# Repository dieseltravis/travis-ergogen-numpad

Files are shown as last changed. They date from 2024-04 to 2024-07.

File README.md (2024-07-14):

# travis-ergogen-numpad
A numpad made with Ergogen v4 and SMD components. *Alpha* quality!

keyboard combo outline

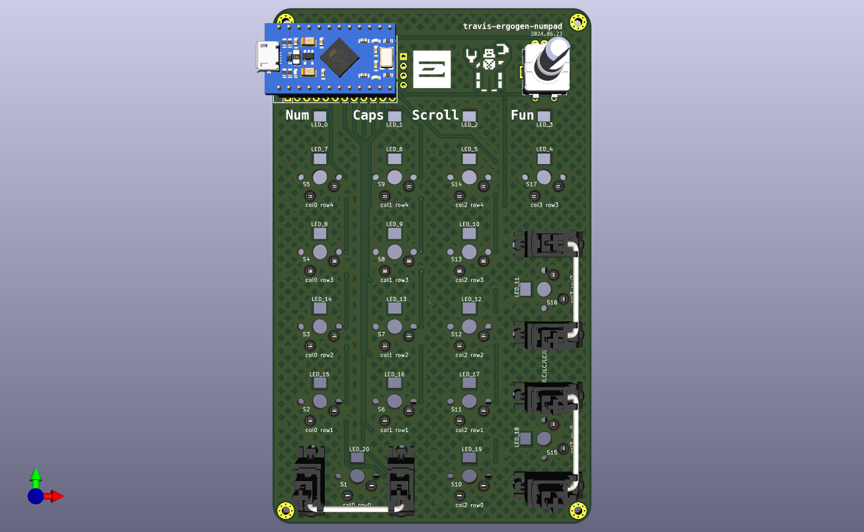
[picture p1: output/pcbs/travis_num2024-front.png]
PCB front


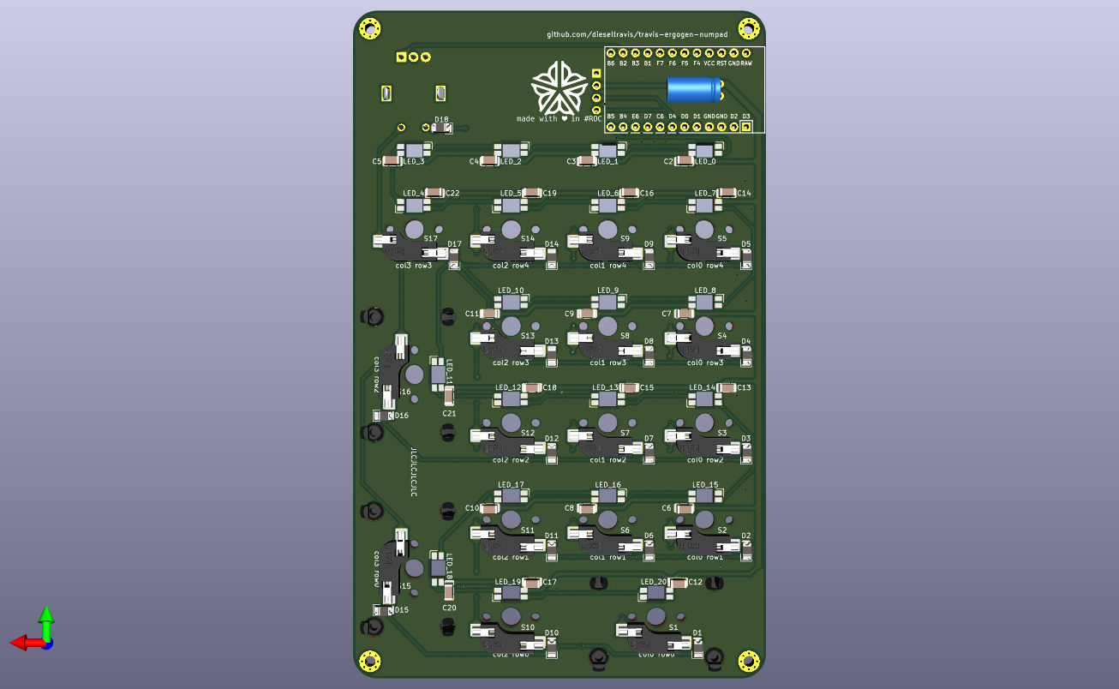
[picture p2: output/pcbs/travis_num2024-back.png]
PCB back


## Parts ##

JLCPCB PCBA:
* 17 @ C5184526 Kailh CPG151101S11-1 Mechanical Keyboard Shaft ROHS https://jlcpcb.com/partdetail/Kailh-CPG151101S111/C5184526
* 18 @ C7420318 hongjiacheng 1N4148W SOD-123 Switching Diode ROHS https://jlcpcb.com/partdetail/hongjiacheng-1N4148W/C7420318
* 21 @ C5149201 OPSCO Optoelectronics SK6812MINI-E SMD RGB LEDs(Built-in IC) ROHS https://jlcpcb.com/partdetail/OPSCOOptoelectronics-SK6812MINIE/C5149201
* 21 @ C710467 HUI JU NM1206B104K251CEGN 100nF X7R ±10% 1206 Multilayer Ceramic Capacitors MLCC - SMD/SMT ROHS https://jlcpcb.com/partdetail/HUIJU-NM1206B104K251CEGN/C710467
* C4747954 KNSCHA RST470UF10V029 470uF 10V 260mA@120Hz ±20% SMD,D6.3xL7.7mm Aluminum Electrolytic Capacitors - SMD ROHS https://jlcpcb.com/partdetail/KNSCHA-RST470UF10V029/C4747954

Aliexpress:
* Rotary encoder: EC11 12.5mm 5pcs https://www.aliexpress.us/item/2251832789732148.html
* RP2040 Pro Micro 16M https://www.aliexpress.us/item/3256805943704472.html
* 0.91 Inch OLED Module 0.91" White Blue 128X32 https://www.aliexpress.us/item/3256805787666312.html

Adafruit:
* 2 @ Kailh Mechanical Key Switches - Tactile Brown - 10 pack - Cherry MX Brown Compatible https://www.adafruit.com/product/4954
* Woven USB Cable with USB A to Right Angle USB C https://www.adafruit.com/product/5031

## References ##

* [sadekbaroudi's QMK RGB Matrix configuration](https://github.com/sadekbaroudi/keyboard-guides/blob/master/firmware/qmk/RGB_MATRIX/RGB_MATRIX.md)
* [my first KB](https://github.com/dieseltravis/travis-ergogen-2024/)

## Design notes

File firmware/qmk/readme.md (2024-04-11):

# dieseltravis/travisergonum

dieseltravis/travisergonum

Ergogen numpad with encoder and screen.

* Keyboard Maintainer: [Travis Hardiman](https://github.com/dieseltravis)
* Hardware Supported: *The PCBs, controllers supported*
* Hardware Availability: *Links to where you can find this hardware*

Make example for this keyboard (after setting up your build environment):

    make dieseltravis/travisergonum:default

Flashing example for this keyboard:

    make dieseltravis/travisergonum:default:flash

See the [build environment setup](https://docs.qmk.fm/#/getting_started_build_tools) and the [make instructions](https://docs.qmk.fm/#/getting_started_make_guide) for more information. Brand new to QMK? Start with our [Complete Newbs Guide](https://docs.qmk.fm/#/newbs).

## Bootloader

Enter the bootloader in 3 ways:

* **Bootmagic reset**: Hold down the key at (0,0) in the matrix (usually the top left key or Escape) and plug in the keyboard
* **Physical reset button**: Briefly press the button on the back of the PCB - some may have pads you must short instead
* **Keycode in layout**: Press the key mapped to `QK_BOOT` if it is available

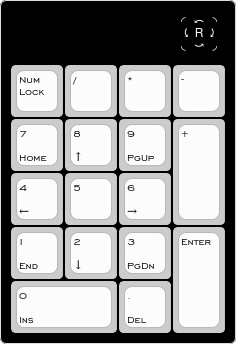
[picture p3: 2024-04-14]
kle/travis-ergonum.png

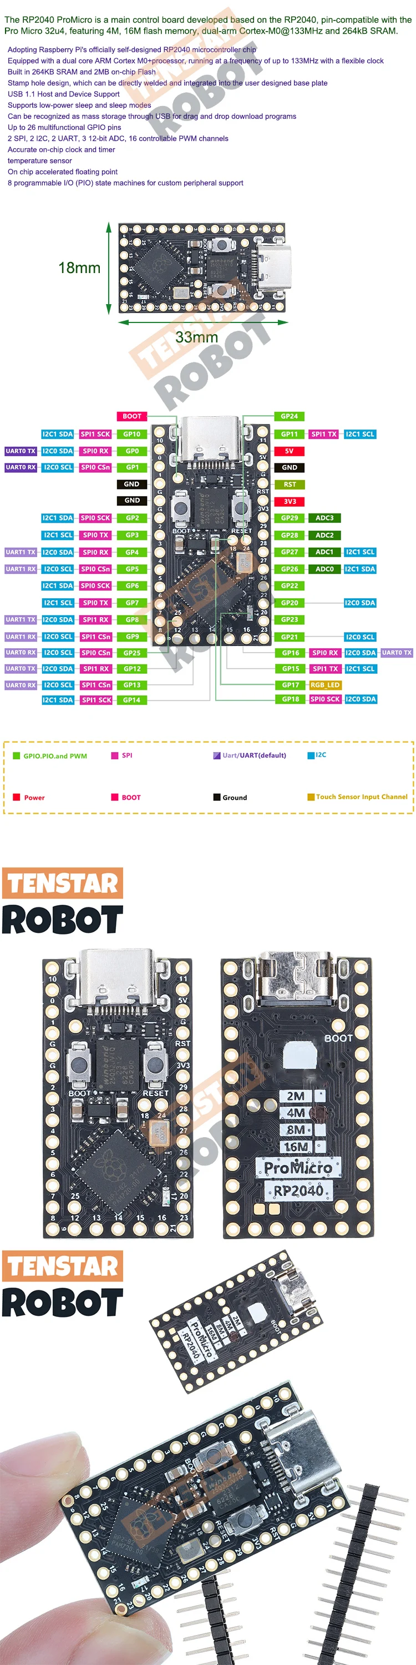
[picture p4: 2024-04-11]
datasheets/rp2040-promicro.webp

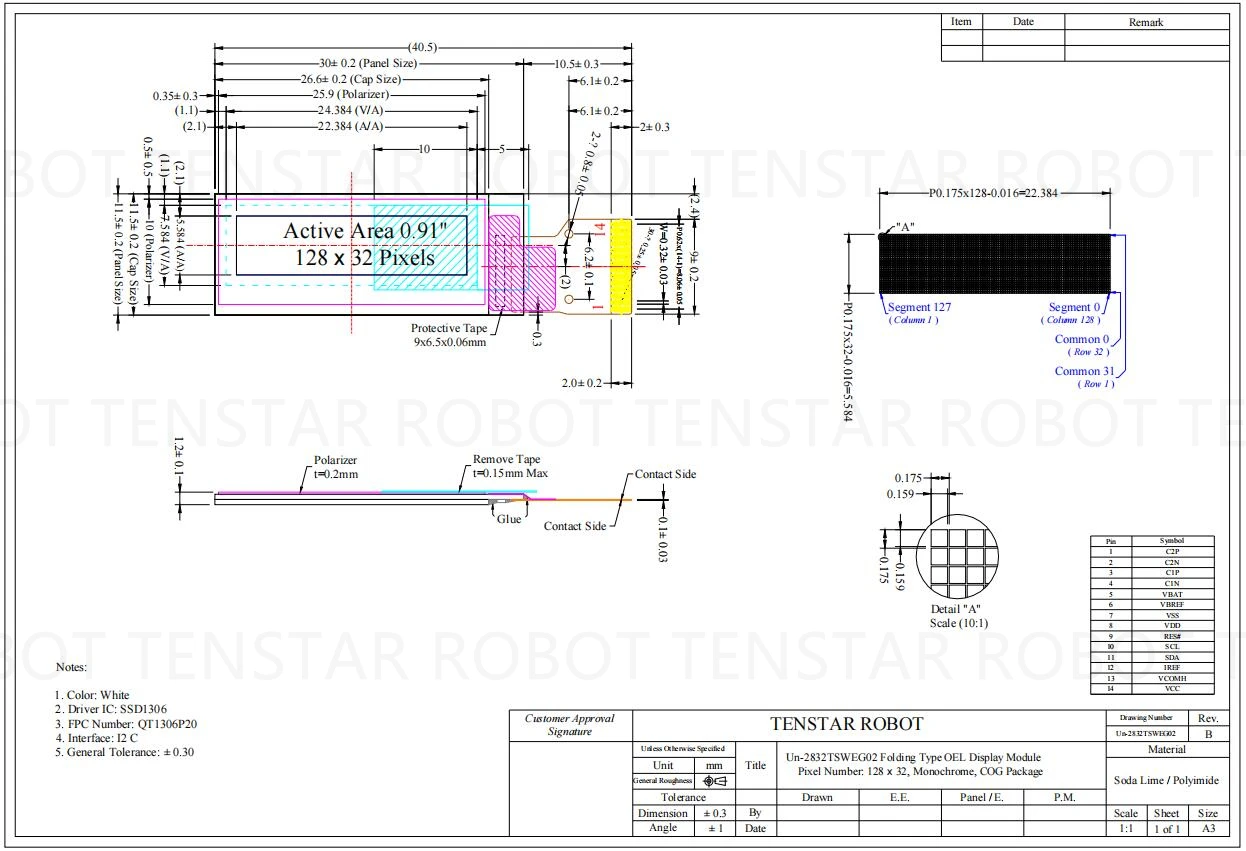
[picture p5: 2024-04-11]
datasheets/ssd1306-128x32.webp

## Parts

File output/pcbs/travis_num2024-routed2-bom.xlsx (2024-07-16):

Id | Designator | Footprint | Quantity | Designation | JLCPCB Part #（optional）
1 | S5,S14,S2,S17,S3,S8,S15,S6,S11,S12,S1,S9,S10,S7,S13,S16,S4 | MX | 17 | Kailh MX Switch Sockets | C5184526
7 | LED_0,LED_12,LED_5,LED_17,LED_3,LED_15,LED_2,LED_1,LED_7,LED_19,LED_18,LED_8,LED_13,LED_4,LED_6,LED_16,LED_9,LED_20,LED_10,LED_14,LED_11 | led_SK6812mini-e (per-key, single-side) | 21 | SK6812mini-e | C5149201
8 | C14,C2,C21,C13,C5,C17,C3,C20,C9,C15,C11,C8,C7,C16,C10,C18,C4,C19,C22,C12,C6 | C_1206_3216Metric | 21 | C_1206_3216Metric | C710467
9 | D3,D18,D14,D6,D17,D8,D1,D16,D12,D2,D13,D4,D10,D9,D15,D5,D11,D7 | D_1206_3216Metric | 18 | D_1206_3216Metric | C7420318

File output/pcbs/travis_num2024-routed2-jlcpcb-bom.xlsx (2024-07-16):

Comment | Designator | Footprint | JLCPCB Part #（optional）
Kailh MX Switch Sockets | S5,S14,S2,S17,S3,S8,S15,S6,S11,S12,S1,S9,S10,S7,S13,S16,S4 | MX | C5184526
SK6812mini-e | LED_0,LED_12,LED_5,LED_17,LED_3,LED_15,LED_2,LED_1,LED_7,LED_19,LED_18,LED_8,LED_13,LED_4,LED_6,LED_16,LED_9,LED_20,LED_10,LED_14,LED_11 | led_SK6812mini-e (per-key, single-side) | C5149201
C_1206_3216Metric | C14,C2,C21,C13,C5,C17,C3,C20,C9,C15,C11,C8,C7,C16,C10,C18,C4,C19,C22,C12,C6 | C_1206_3216Metric | C710467
D_1206_3216Metric | D3,D18,D14,D6,D17,D8,D1,D16,D12,D2,D13,D4,D10,D9,D15,D5,D11,D7 | D_1206_3216Metric | C7420318

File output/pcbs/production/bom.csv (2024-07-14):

Designator | Footprint | Quantity | Value | LCSC Part #
C1 | C_Radial_D6.3mm_H11.0mm_P2.50mm | 1 | 6.3V 1000uF
C10, C11, C12, C13, C14, C15, C16, C17, C18, C19, C2, C20, C21, C22, C3, C4, C5, C6, C7, C8, C9 | 1206 | 21 | C_1206_3216Metric
D1, D10, D11, D12, D13, D14, D15, D16, D17, D18, D2, D3, D4, D5, D6, D7, D8, D9 | 1206 | 18 | D_1206_3216Metric
HOLE1, HOLE2, HOLE3, HOLE4 | MountingHole_2.2mm_M2_Pad_Via | 4
LED_0, LED_1, LED_10, LED_11, LED_12, LED_13, LED_14, LED_15, LED_16, LED_17, LED_18, LED_19, LED_2, LED_20, LED_3, LED_4, LED_5, LED_6, LED_7, LED_8, LED_9 | led_SK6812mini-e (per-key, single-side) | 21 | SK6812mini-e
MCU1 | Arduino_Pro_Micro | 1 | Arduino Pro Micro
OLED1 | OLED_headers | 1 | OLED
ROT1 | ec11 | 1 | EC11
S1, S10, S11, S12, S13, S14, S15, S16, S17, S2, S3, S4, S5, S6, S7, S8, S9 | MX | 17 | Kailh MX Switch Sockets

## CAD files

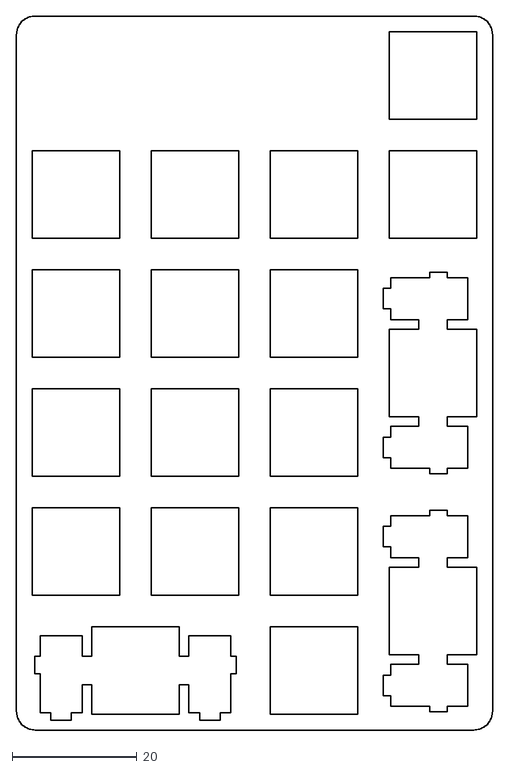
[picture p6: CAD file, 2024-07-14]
kle/plate.dxf
76.2 x 114.3

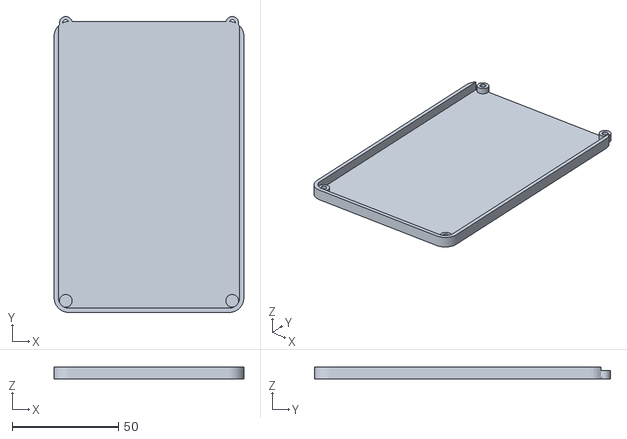
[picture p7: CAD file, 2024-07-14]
output/cases/case.stl
89.2 x 139.1 x 5.60

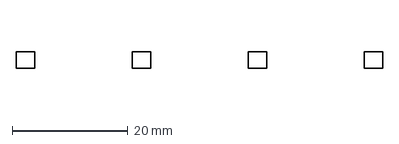
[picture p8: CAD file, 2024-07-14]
output/outlines/leds.dxf
63.4 x 2.80 mm

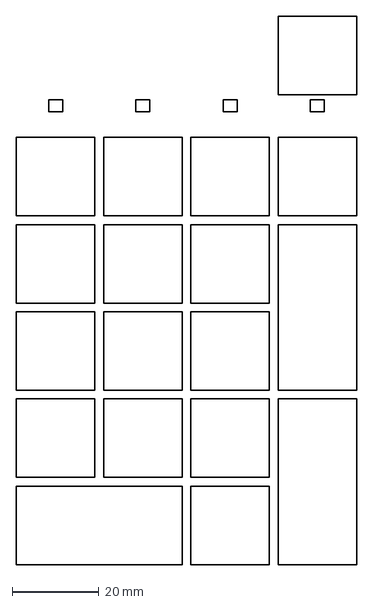
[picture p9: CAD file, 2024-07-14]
output/points/demo.dxf
78.2 x 126.1 mm

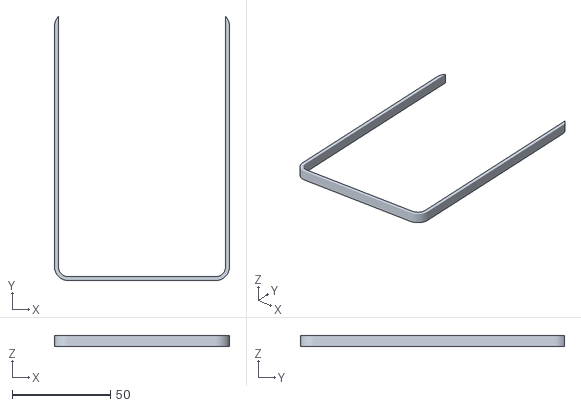
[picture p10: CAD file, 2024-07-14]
output/cases/wall.stl
89.2 x 134.6 x 5.60

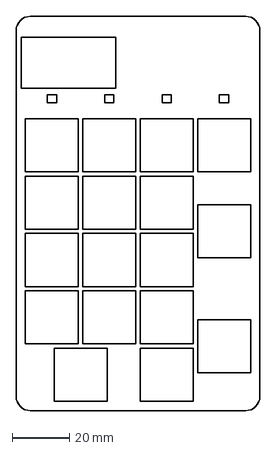
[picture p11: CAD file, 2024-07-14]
output/outlines/combo.dxf
85.2 x 137.8 mm

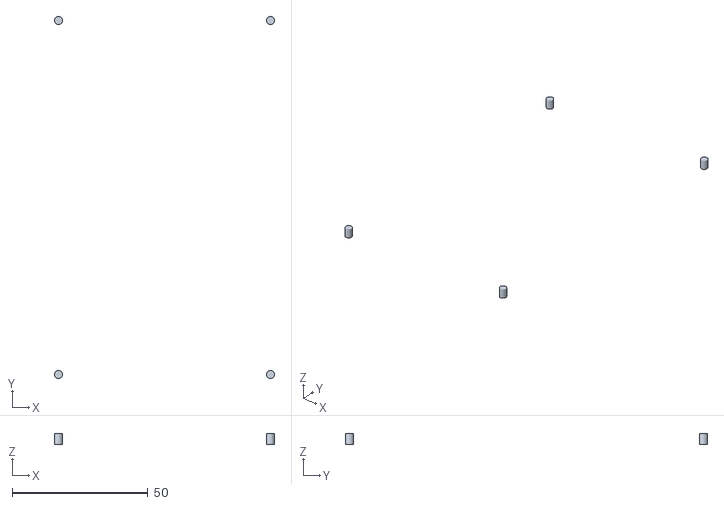
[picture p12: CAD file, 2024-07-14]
output/cases/_holes.stl
81.2 x 133.6 x 4.00

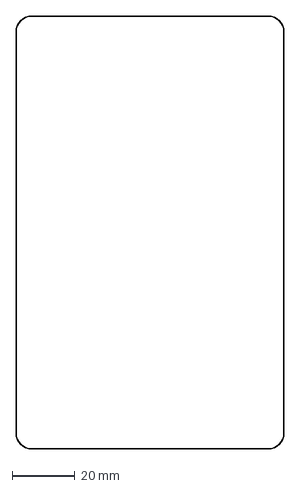
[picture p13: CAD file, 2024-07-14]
output/outlines/board.dxf
85.2 x 137.8 mm

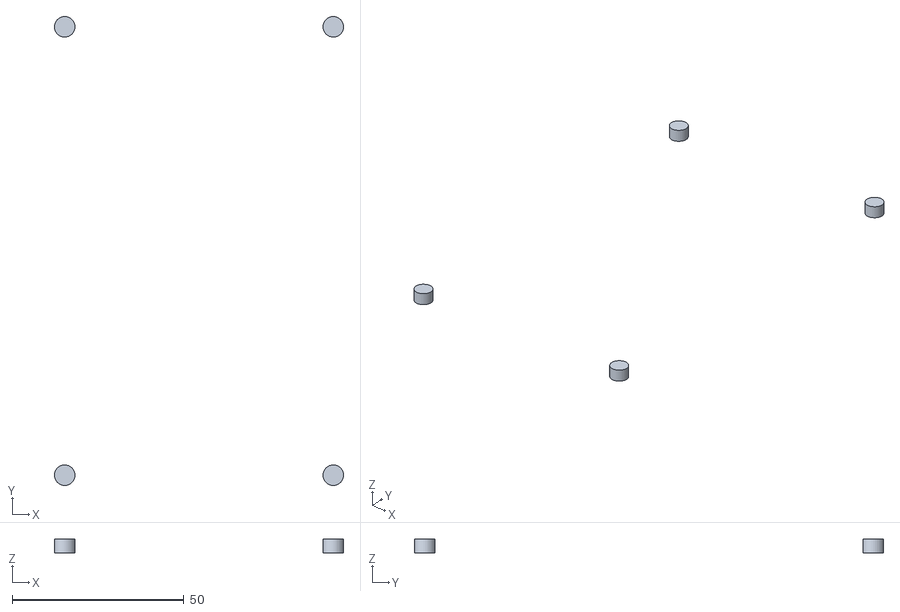
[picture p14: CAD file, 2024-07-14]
output/cases/_standoffs.stl
84.2 x 136.6 x 4.00

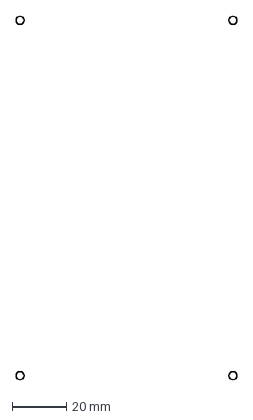
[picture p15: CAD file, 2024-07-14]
output/outlines/mounting.dxf
81.2 x 133.6 mm

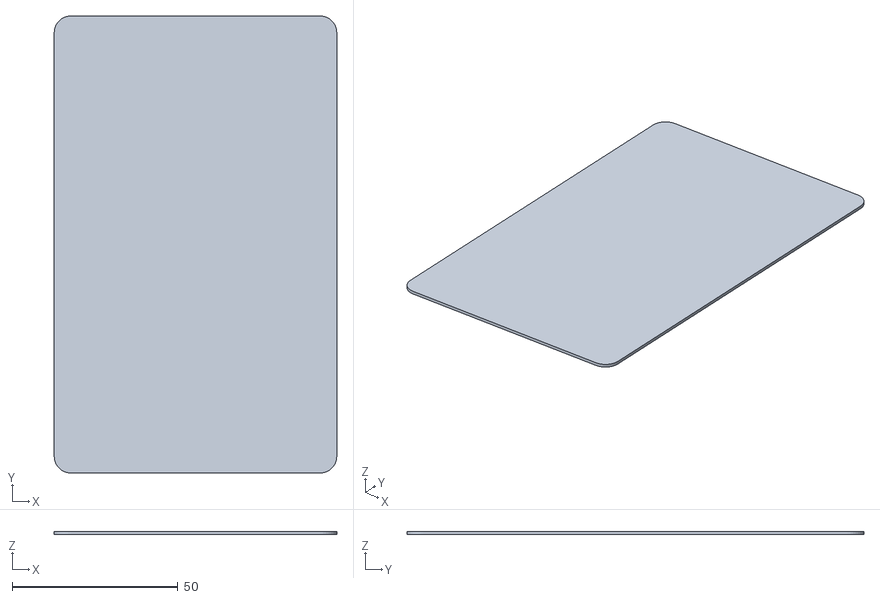
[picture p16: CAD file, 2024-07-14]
output/cases/bottom.stl
85.2 x 137.8 x 1.00

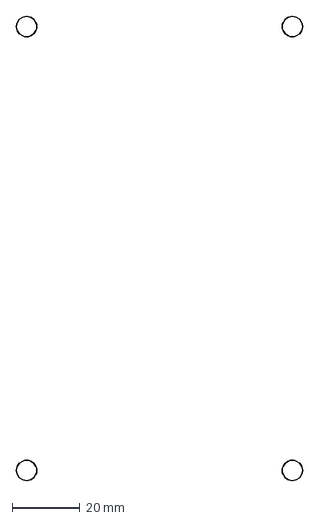
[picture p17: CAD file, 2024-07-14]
output/outlines/standoff.dxf
84.2 x 136.6 mm

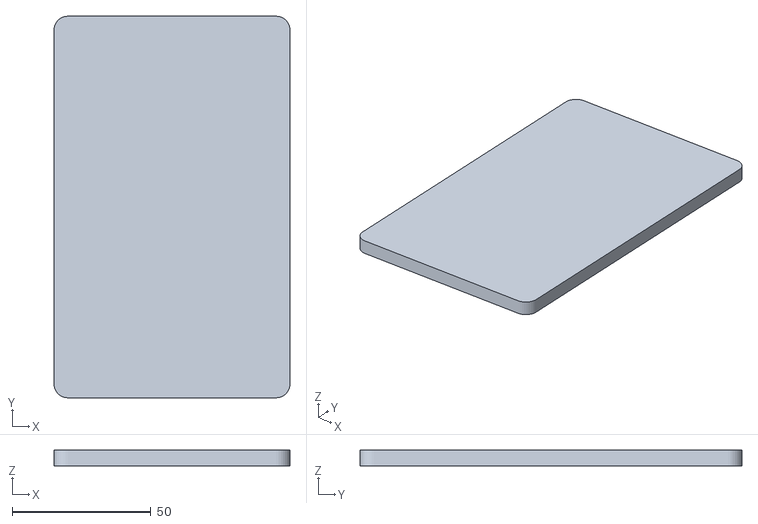
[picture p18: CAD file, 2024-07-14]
output/cases/_innerWall.stl
85.2 x 137.8 x 5.60

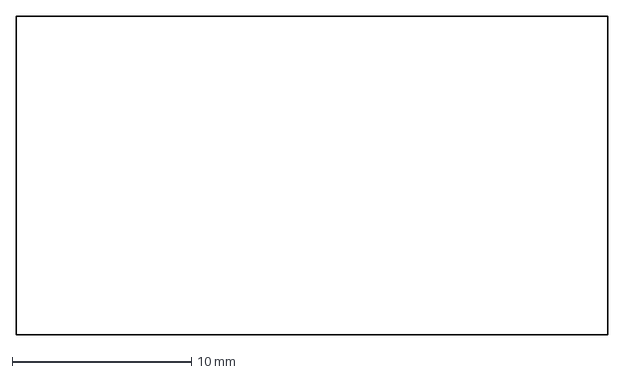
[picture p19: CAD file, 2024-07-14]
output/outlines/mcu.dxf
33.0 x 17.8 mm

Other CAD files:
output/cases/plate.stl
output/outlines/plate.dxf
output/cases/_outerWall.stl
output/outlines/2u_stabilizer.dxf
output/cases/xlBottom.stl
output/outlines/_raw.dxf
output/outlines/keyholes.dxf
output/outlines/keys.dxf
output/outlines/raw.dxf
output/outlines/smBoard.dxf
output/outlines/xlBoard.dxf

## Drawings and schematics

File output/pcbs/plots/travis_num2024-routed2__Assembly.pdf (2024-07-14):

1 | 2 | 3 | 4 | 5 | 6 | 7 | 8

A

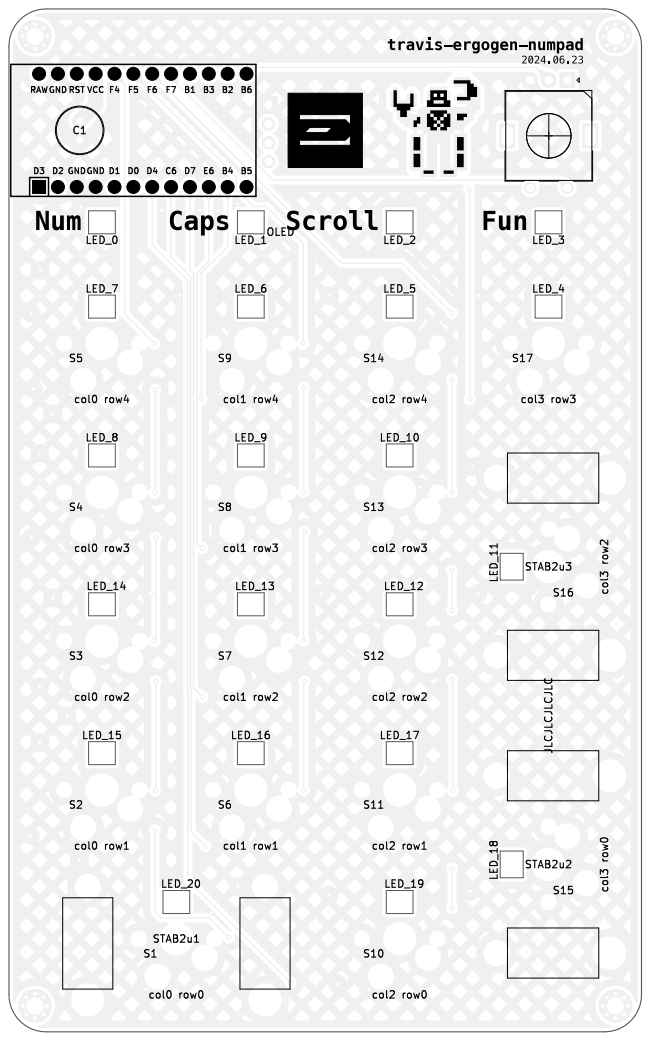
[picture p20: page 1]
col0 row1; col0 row3; LED_19 Scroll; LED_7; LED_15; travis-ergogen-numpad LED_18; Num; col2 row3; LED_20; col3 row⁰col2 row1; LED_8; LED_17; col1 row1; col1 row2; LED_14; LED_5; col1 row4; col2 row4; col2 row2; col0 row0; LED_13; col1 row3; col3 row3; LED_6; LED_10; JLCJLCJLCJLC; col3 row²; LED_12; LED_16; LED_3; col0 row2; LED_2; LED_4; LED_1; col0 row4; LED_9; LED_0; FunLED_11; col2 row0 Caps; B2 E6 RAW; D2 GND GND; B6B5 RST; B4 F7 GND; D4 VCC; F Date: 2024-06-24 KiCad; E.D.A. 8.0.3 Size: A3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

File: travis_num2024-routed2.kicad_pcb Sheet: Travis Hardiman

1 | 2 | 3 | 4 | 5 | 6 | 7 | 8

A

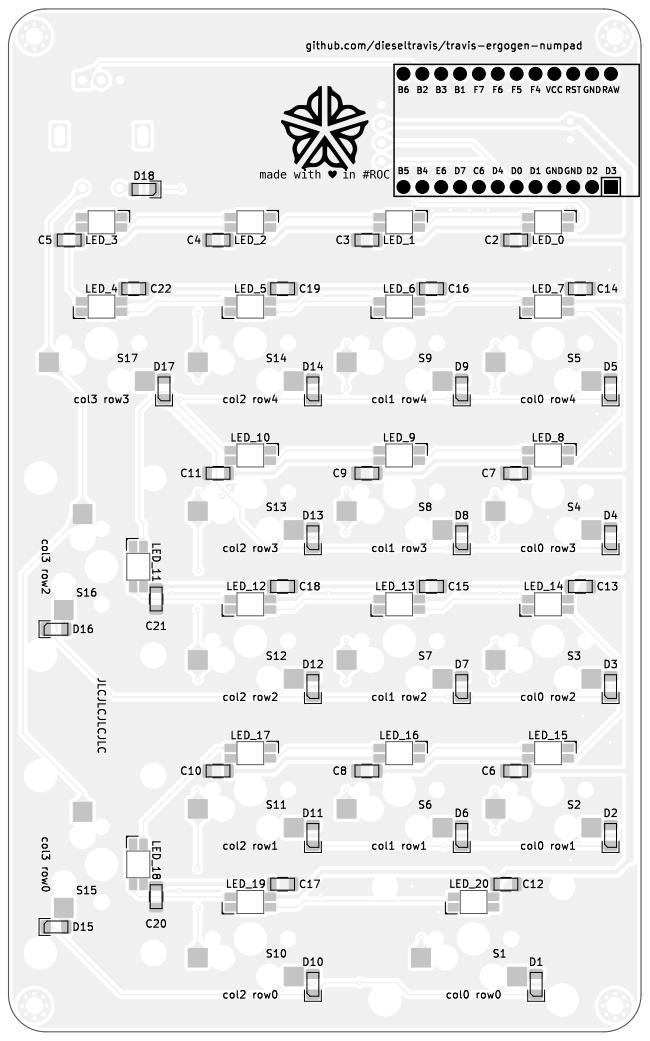
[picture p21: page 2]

github.com/dieseltravis/travis-ergogen-numpad S16

S5 made with þÿ&ein #ROC

File: travis_num2024-routed2.kicad_pcb Sheet: Travis Hardiman

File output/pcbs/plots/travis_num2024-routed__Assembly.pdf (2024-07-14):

1 | 2 | 3 | 4 | 5 | 6 | 7 | 8

A

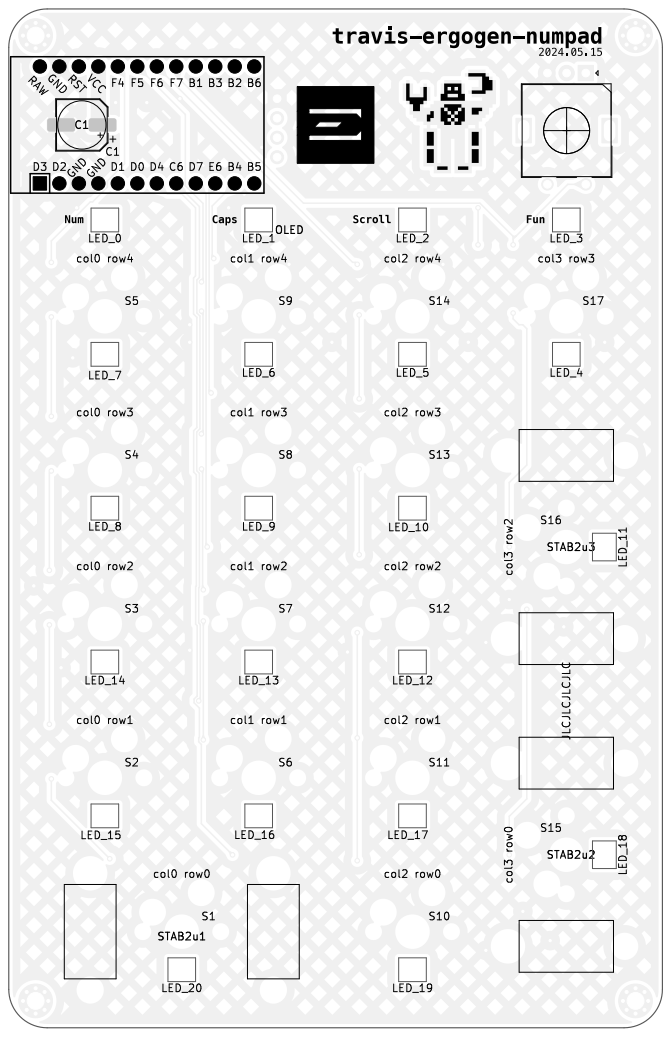
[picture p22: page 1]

File: travis_num2024-routed.kicad_pcb Sheet: Travis Hardiman

1 | 2 | 3 | 4 | 5 | 6 | 7 | 8

A

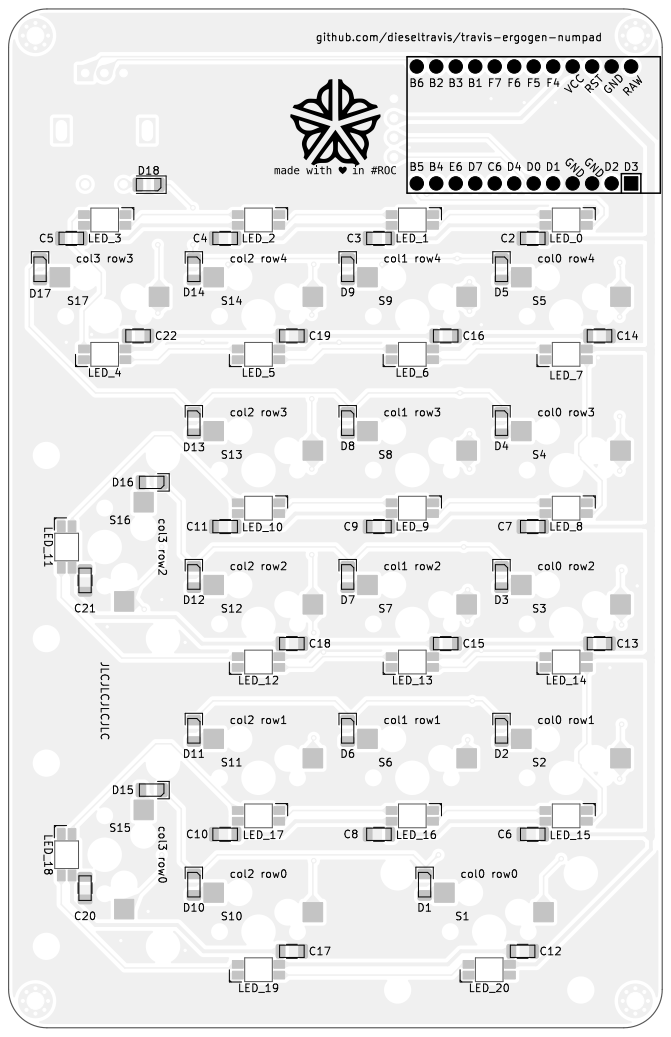
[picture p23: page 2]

github.com/dieseltravis/travis-ergogen-numpad

File: travis_num2024-routed.kicad_pcb Sheet: Travis Hardiman

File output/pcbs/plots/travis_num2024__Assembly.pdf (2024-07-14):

1 | 2 | 3 | 4 | 5 | 6 | 7 | 8

A

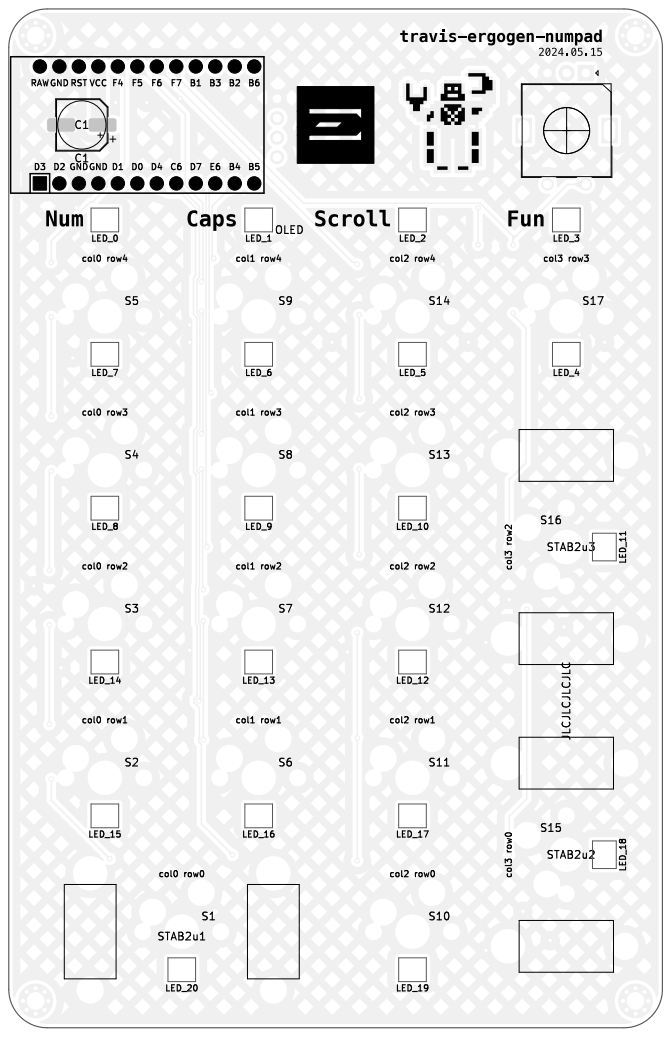
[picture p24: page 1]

File: travis_num2024.kicad_pcb Sheet: Travis Hardiman

1 | 2 | 3 | 4 | 5 | 6 | 7 | 8

A

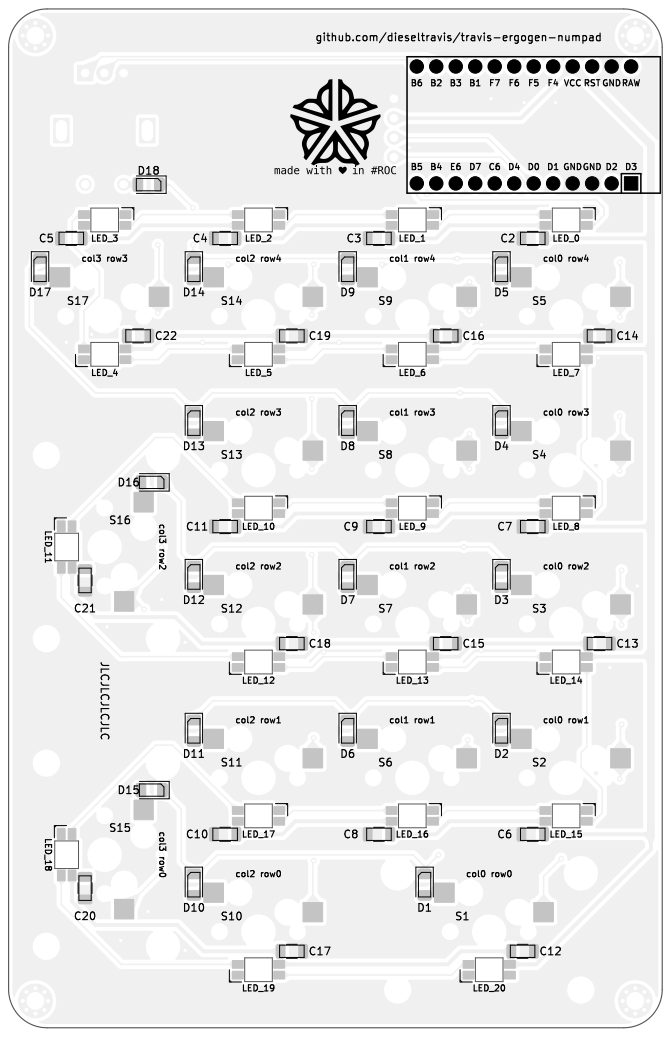
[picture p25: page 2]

github.com/dieseltravis/travis-ergogen-numpad JLCJLCJLCJLC
col2 row4 col3 row0 col3 row2
LED_5 LED_18 LED_11

B5 B4 E6 D7 C6 D4 D0 D1 GNDGND D2 D3 B6 B2 B3 B1 F7 F6 F5 F4 VCC RST GNDRAW

File: travis_num2024.kicad_pcb Sheet: Travis Hardiman

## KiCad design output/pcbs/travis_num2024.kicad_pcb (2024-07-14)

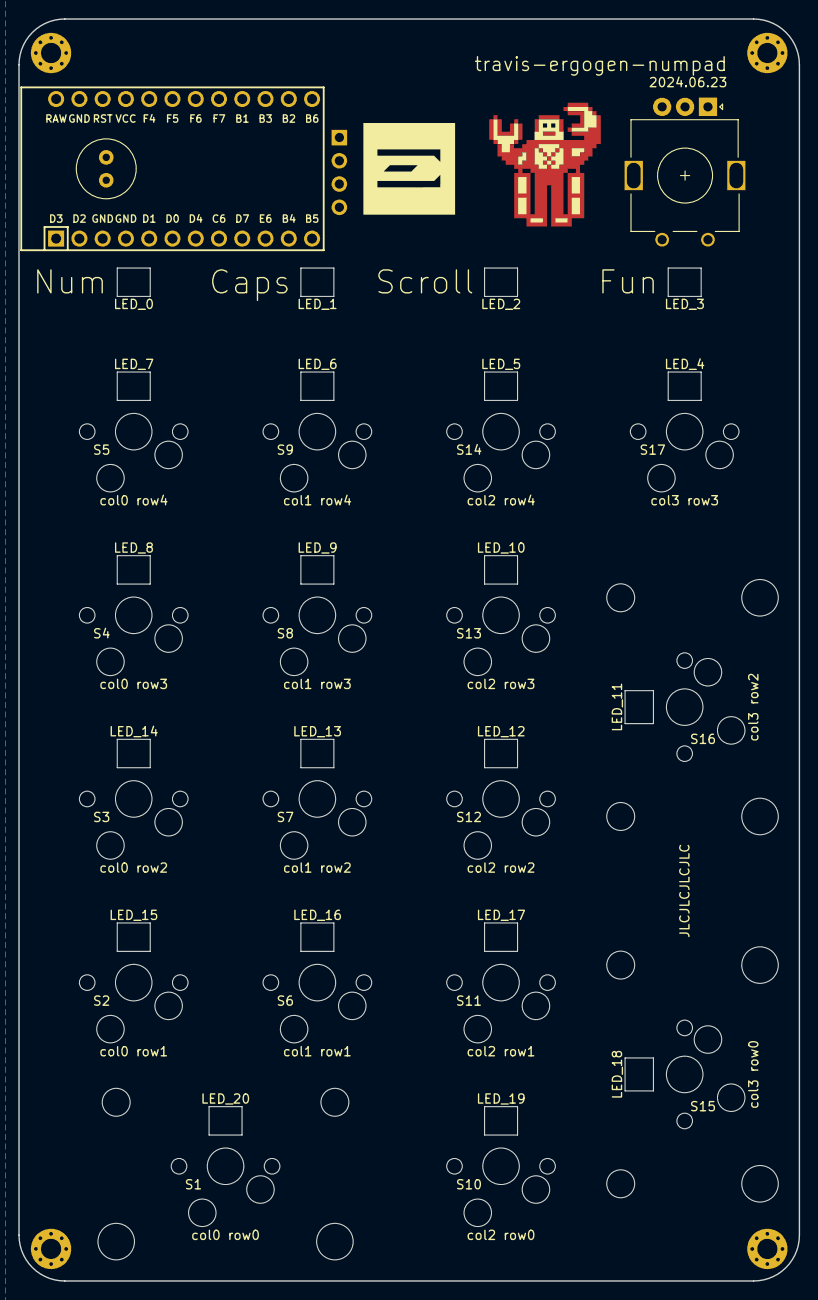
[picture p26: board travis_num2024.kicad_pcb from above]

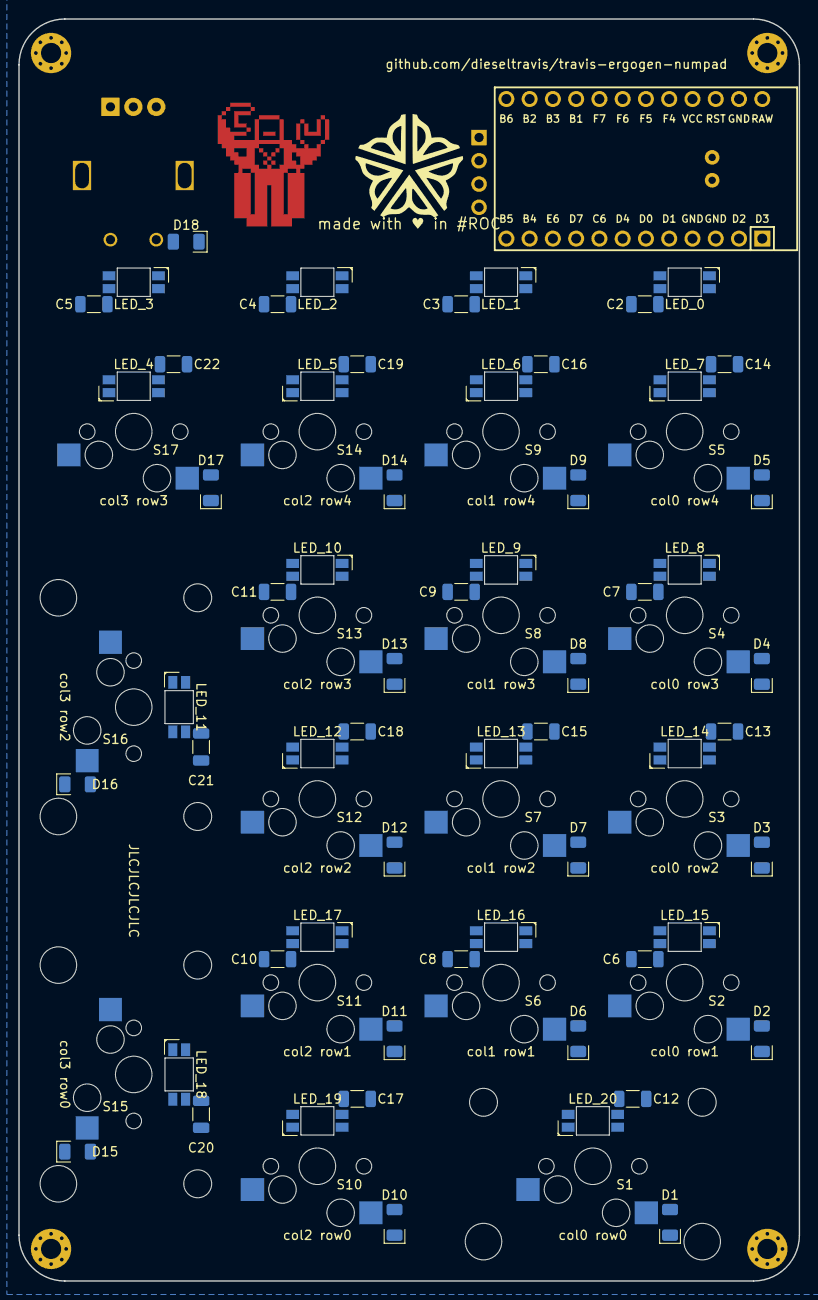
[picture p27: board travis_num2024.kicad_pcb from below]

Board: 2 copper layers, 85.2 x 137.8 mm, 91 parts (61 on the bottom side), 54 nets, no tracks yet.

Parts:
C1: 6.3V 1000uF; C_Radial_D6.3mm_H11.0mm_P2.50mm
C2, C3, C4, C5, C6, C7, C8, C9, C10, C11, C12, C13, C14, C15, C16, C17, C18, C19, C20, C21, C22: C_1206_3216Metric
D1, D2, D3, D4, D5, D6, D7, D8, D9, D10, D11, D12, D13, D14, D15, D16, D17, D18: D_1206_3216Metric
HOLE1, HOLE2, HOLE3, HOLE4: MountingHole_2.2mm_M2_Pad_Via
LED1, LED2, LED3, LED4, LED5, LED6, LED7, LED8, LED9, LED10, LED11, LED12, LED13, LED14, LED15, LED16, LED17, LED18, LED19, LED20, LED21: SK6812mini-e; led_SK6812mini-e (per-key, single-side)
LOGO1: utility_ergogen_logo
LOGO2: travis
MCU1: Arduino Pro Micro; Arduino_Pro_Micro
OLED1: OLED; OLED_headers
ROC1: travis
ROT1: EC11; ec11
S1, S2, S3, S4, S5, S6, S7, S8, S9, S10, S11, S12, S13, S14, S15, S16, S17: Kailh MX Switch Sockets; MX
STAB2u1, STAB2u2, STAB2u3: Stabilizer_MX_2.00u

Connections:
GND: C1.2, C2.2, C3.2, C4.2, C5.2, C6.2, C7.2, C8.2, C9.2, C10.2, C11.2, C12.2, C13.2, C14.2, C15.2, C16.2, C17.2, C18.2, C19.2, C20.2, C21.2, C22.2, LED1.3, LED2.3, LED3.3, LED4.3, LED5.3, LED6.3, LED7.3, LED8.3, LED9.3, LED10.3, LED11.3, LED12.3, LED13.3, LED14.3, LED15.3, LED16.3, LED17.3, LED18.3, LED19.3, LED20.3, LED21.3, MCU1.3, MCU1.4, MCU1.23, OLED1.1, ROT1.B
LED_0: LED1.4, MCU1.12
LED_1: LED1.2, LED2.4
LED_2: LED2.2, LED3.4
LED_3: LED3.2, LED4.4
LED_4: LED4.2, LED21.4
LED_5: LED18.4, LED21.2
LED_6: LED15.4, LED18.2
LED_7: LED13.4, LED15.2
LED_8: LED6.4, LED13.2
LED_9: LED6.2, LED8.4
LED_10: LED8.2, LED10.4
LED_11: LED10.2, LED20.4
LED_12: LED17.4, LED20.2
LED_13: LED14.4, LED17.2
LED_14: LED12.4, LED14.2
LED_15: LED5.4, LED12.2
LED_16: LED5.2, LED7.4
LED_17: LED7.2, LED9.4
LED_18: LED9.2, LED19.4
LED_19: LED16.4, LED19.2
LED_20: LED11.4, LED16.2
VCC: C1.1, C2.1, C3.1, C4.1, C5.1, C6.1, C7.1, C8.1, C9.1, C10.1, C11.1, C12.1, C13.1, C14.1, C15.1, C16.1, C17.1, C18.1, C19.1, C20.1, C21.1, C22.1, LED1.1, LED2.1, LED3.1, LED4.1, LED5.1, LED6.1, LED7.1, LED8.1, LED9.1, LED10.1, LED11.1, LED12.1, LED13.1, LED14.1, LED15.1, LED16.1, LED17.1, LED18.1, LED19.1, LED20.1, LED21.1, MCU1.21, OLED1.2
col0: MCU1.20, S1.1, S2.1, S3.1, S4.1, S5.1
col1: MCU1.19, S6.1, S7.1, S8.1, S9.1
col2: MCU1.18, S10.1, S11.1, S12.1, S13.1, S14.1
col3: MCU1.17, ROT1.1, S15.1, S16.1, S17.1
encA: MCU1.14, ROT1.A
encC: MCU1.13, ROT1.C
enc_to: D18.2, ROT1.2
matrix_col0_row0: D1.2, S1.2
matrix_col0_row1: D2.2, S2.2
matrix_col0_row2: D3.2, S3.2
matrix_col0_row3: D4.2, S4.2
matrix_col0_row4: D5.2, S5.2
matrix_col1_row1: D6.2, S6.2
matrix_col1_row2: D7.2, S7.2
matrix_col1_row3: D8.2, S8.2
matrix_col1_row4: D9.2, S9.2
matrix_col2_row0: D10.2, S10.2
matrix_col2_row1: D11.2, S11.2
matrix_col2_row2: D12.2, S12.2
matrix_col2_row3: D13.2, S13.2
matrix_col2_row4: D14.2, S14.2
matrix_col3_row0: D15.2, S15.2
matrix_col3_row2: D16.2, S16.2
matrix_col3_row4: D17.2, S17.2
row0: D1.1, D10.1, D15.1, MCU1.7
row1: D2.1, D6.1, D11.1, MCU1.8
row2: D3.1, D7.1, D12.1, D16.1, MCU1.9
row3: D4.1, D8.1, D13.1, D17.1, MCU1.10
row4: D5.1, D9.1, D14.1, D18.1, MCU1.11
scl: MCU1.6, OLED1.3
sda: MCU1.5, OLED1.4

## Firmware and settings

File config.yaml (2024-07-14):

meta:
  engine: 4.1.0
  name: "travis-ergogen-numpad"
  version: &meta_version "2024.06.23"
  date: "2024-06-23"
  author: "Travis Hardiman"
  url: &url github.com/dieseltravis/travis-ergogen-numpad
  tags: [ "ergogen", "promicro", "keyboard", "cherrymx", "hotswap", "rgb", "numpad", "smd" ]
units:
  u: U
  pp: U + 2
  # outer perimeter of board
  op: U + 6
  kp: U + 1
  smp: 1.2
  xlp: 2
  # plate switch width
  pw: 14
  # Defaults to M2 Screws
  #screwSize: 1
  # M2 Screw Inserts
  screwSize: 1.5
  standoffSize: 3.0
  top_y: 0.5U - 0.5 + 16
  bot_y: -0.5U + 0.5
  left_x: -0.5U + 0.5
  right_x: 0.5U - 0.5
  # bottom case thickness
  bt: 1
  # gap below pcb and case
  gt: 3
  # pcb thickness
  pt: 1.6
  # stab Y adjust
  staby: 0
  # indicator led labels
  lblsize: 2.5
  lblshift: -2.75
  # stabs
  stabilizer_width: 7 
  stabilizer_height: 16
  stabilizer_offset: 0 # This means south stabs, use `orient` to rotate them for north facing scenarios
  stabilizer_spacing_3u: U * ((3 - 1) / 2)
  stabilizer_spacing_2u: 23.86 / 2 # 0.94in / 2
points:
  zones:
    matrix:
      anchor:
        # move the PCB into view for KiCad
        shift: [40, -200]
      key:
        padding: kp
        spread: kp
      columns:
        col0:
          key:
            column_net: col0
          rows:
            row0:
              width: 2U
              shift: [0.5kp, 0]
              tags:
                - key
                - 2u_stabilizers
                - row_even
              key:
                led_next: ""
                led_this: LED_20
            row1:
              shift: [-0.5kp, 0]
              key:
                led_next: LED_16
                led_this: LED_15
            row2:
              key:
                led_next: LED_15
                led_this: LED_14
            row3:
              key:
                led_next: LED_9
                led_this: LED_8
            row4:
              key:
                led_next: LED_8
                led_this: LED_7
        col1:
          key:
            column_net: col1
          rows:
            row0:
              skip: true
            row1:
              key:
                led_next: LED_17
                led_this: LED_16
            row2:
              key:
                led_next: LED_14
                led_this: LED_13
            row3:
              key:
                led_next: LED_10
                led_this: LED_9
            row4:
              key:
                led_next: LED_7
                led_this: LED_6
        col2:
          key:
            column_net: col2
          rows:
            row0:
              key:
                led_next: LED_20
                led_this: LED_19
            row1:
              key:
                led_next: LED_18
                led_this: LED_17
            row2:
              key:
                led_next: LED_13
                led_this: LED_12
            row3:
              key:
                led_next: LED_11
                led_this: LED_10
            row4:
              key:
                led_next: LED_6
                led_this: LED_5
        col3:
          key:
            column_net: col3
          rows:
            row0:
              shift: [0, 0.5kp]
              rotate: 90
              width: 2U
              tags:
                - key
                - 2u_stabilizers
                - row_even
              key:
                led_next: LED_19
                led_this: LED_18
            row1: 
              rotate: -90
              shift: [1kp, -1kp]
              skip: true
            row2:
              rotate: 90
              width: 2U
              tags:
                - key
                - 2u_stabilizers
                - row_even
              key:
                led_next: LED_12
                led_this: LED_11
            row3:
              rotate: -90
              shift: [0.5kp, -1kp]
              skip: true
            row4:
              row_net: row3
              key:
                led_next: LED_5
                led_this: LED_4
      rows:
        row0:
          tags: 
            - key
            - row_even
          row_net: row0
        row1:
          tags: 
            - key
            - row_odd
          row_net: row1
        row2:
          tags: 
            - key
            - row_even
          row_net: row2
        row3:
          tags: 
            - key
            - row_odd
          row_net: row3
        row4:
          tags: 
            - key
            - row_even
          row_net: row4
    indicators:
      key:
        padding: kp
        spread: kp
      anchor:
        ref: matrix_col0_row4
        shift: [0, 1.25U]
      columns:
        col0:
          rows:
            row5:
              key:
                led_next: LED_1
                led_this: LED_0
                led_power: RAWD
        col1:
          rows:
            row5:
              key:
                led_next: LED_2
                led_this: LED_1
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

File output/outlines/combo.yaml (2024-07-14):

models:
    export:
        models:
            a:
                models:
                    a:
                        models:
                            a:
                                models:
                                    a:
                                        models: {}
                                        origin:
                                            - 0
                                            - 0
                                    b:
                                        models:
                                            a:
                                                models: {}
                                                origin:
                                                    - 0
                                                    - 0
                                            b:
                                                paths:
                                                    p1:
                                                        type: line
                                                        origin:
                                                            - 27.474999999999998
                                                            - -207.525
                                                        end:
                                                            - 27.474999999999998
                                                            - -79.74999999999997
                                                    p2:
                                                        type: line
                                                        origin:
                                                            - 32.474999999999994
                                                            - -74.74999999999997
                                                        end:
                                                            - 107.67500000000001
                                                            - -74.74999999999997
                                                    p3:
                                                        type: line
                                                        origin:
                                                            - 112.67500000000001
                                                            - -79.74999999999997
                                                        end:
                                                            - 112.67500000000001
                                                            - -207.525
                                                    p4:
                                                        type: line
                                                        origin:
                                                            - 107.67500000000001
                                                            - -212.525
                                                        end:
                                                            - 32.474999999999994
                                                            - -212.525
                                                origin:
                                                    - 0
                                                    - 0
                                            fillet_0_0:
                                                paths:
                                                    fillet0:
                                                        origin:
                                                            - 32.474999999999994
                                                            - -79.74999999999997
                                                        radius: 5
                                                        startAngle: 90
                                                        endAngle: 180
                                                        type: arc
                                                    fillet1:
                                                        origin:
                                                            - 107.67500000000001
                                                            - -79.74999999999997
                                                        radius: 5
                                                        startAngle: 0
                                                        endAngle: 90
                                                        type: arc
                                                    fillet2:
                                                        origin:
                                                            - 107.67500000000001
                                                            - -207.525
                                                        radius: 5
                                                        startAngle: 270
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

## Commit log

2024-04-07 submod footprint
2024-04-09 mcu, leds, spacing
    [board.dxf, combo.dxf, keys.dxf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]
2024-04-10 debug output
    [_raw.dxf, demo.dxf]
2024-04-10 fixed output
    [travis_num2024.kicad_pcb]
2024-04-10 numpad basic layout
    [travis_num2024.kicad_pcb]
2024-04-11 layout and label fixes
    [travis_num2024.kicad_pcb]
2024-04-12 roc logo on back
    [travis_num2024.kicad_pcb]
2024-04-13 holes, roc text
    [travis_num2024.kicad_pcb]
2024-04-13 text and cap fixes
    [travis_num2024.kicad_pcb]
2024-04-13 numpad routed, with outputs
    [bom.csv, designators.csv, positions.csv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]
2024-04-13 fixed rows, re-routed
    [bom.csv, designators.csv, positions.csv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]
2024-04-13 route 1 adjust
    [travis_num2024-route1.dsn, travis_num2024-route1.kicad_pcb, travis_num2024-route2.kicad_pcb]
2024-04-14 led fix
    [travis_num2024-route2.kicad_pcb, travis_num2024-route2.kicad_pcb_bom.csv, travis_num2024-route2.kicad_pcb_positions.csv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]
2024-04-14 update footprints
2024-04-14 plate work
    [keyholes.dxf, plate.dxf, smBoard.dxf]
2024-04-14 plate 3d
2024-04-14 plate 3d, kle
    [plate.stl]
2024-04-24 working on plate
    [2u_stabilizer.dxf, demo.dxf, plate.dxf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]
2024-05-10 updated footprints and ergogen
2024-05-11 new footprints for smd components
    [travis_num2024.kicad_pcb]
2024-05-13 smd progress
    [travis_num2024.kicad_pcb]
2024-05-16 smd progress, labels added
    [travis_num2024-route3.kicad_pcb, travis_num2024.kicad_pcb]
2024-06-17 kb placer testing
    [plate.dxf, travis_num2024.kicad_sch]
2024-06-22 numpad cap and firmware
    [bom.csv, positions.csv, travis_num2024.kicad_pcb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]
2024-06-23 added zones, fixed leds, caps
    [_holes.stl, _innerWall.stl, _standoffs.stl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]
2024-06-24 routed v2
    [positions.csv, travis_num2024-routed2.csv, travis_num2024-routed2.kicad_pcb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]
2024-06-25 added qmk led layout & recompiled for ce
    [bom.csv, designators.csv, positions.csv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]
2024-07-03 via firmware
    [travis_num2024-routed2-bom.xlsx, travis_num2024-routed2-jlcpcb-bom.xlsx, travis_num2024-routed2-jlcpcb-bom2.xlsx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]
